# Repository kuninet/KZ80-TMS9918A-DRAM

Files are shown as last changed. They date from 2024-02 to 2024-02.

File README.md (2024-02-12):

# KZ80シリーズ TMS9918A ビデオボード(DRAM版)

## 概要

* SBC8080バスにつながるTMS9918Aビデオボードのプロジェクトです。
* 以下のリポジトリからFORKしたかたちで、SRAM版からDRAM版へ変更したリポジトリです。
  * https://github.com/kuninet/KZ80-TMS9918A

### 4464 64kbit x 4bit DRAM版

#### 回路図

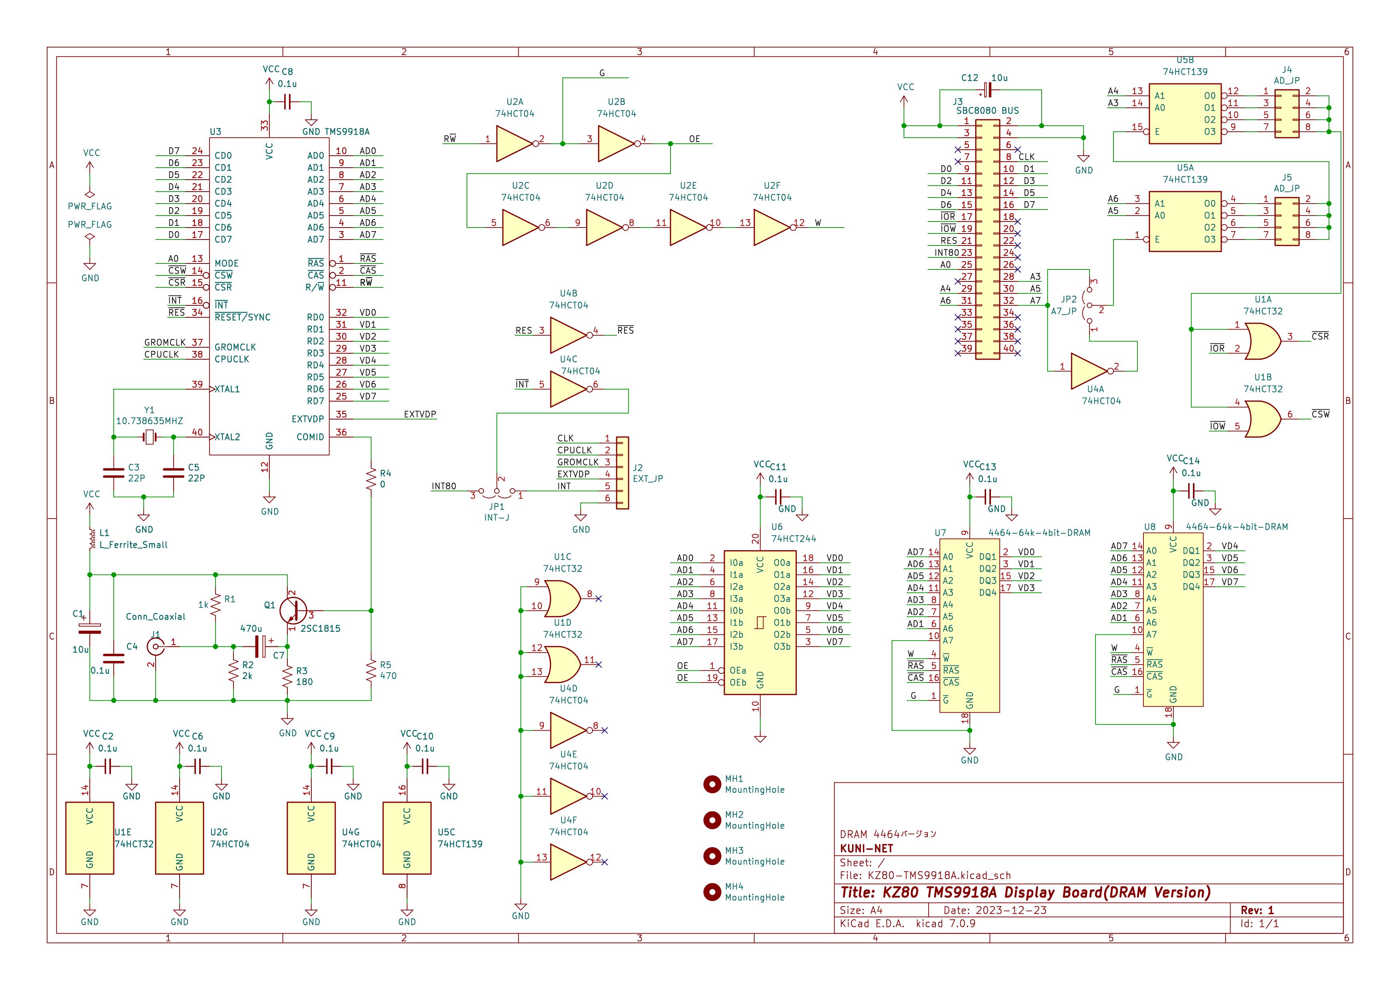
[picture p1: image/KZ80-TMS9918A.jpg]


#### 部品表

[KiCAD/KZ80-TMS9918A.csv](KiCAD/KZ80-TMS9918A.csv)

### MB8118 16kbit x 1bit DRAM版

#### 回路図

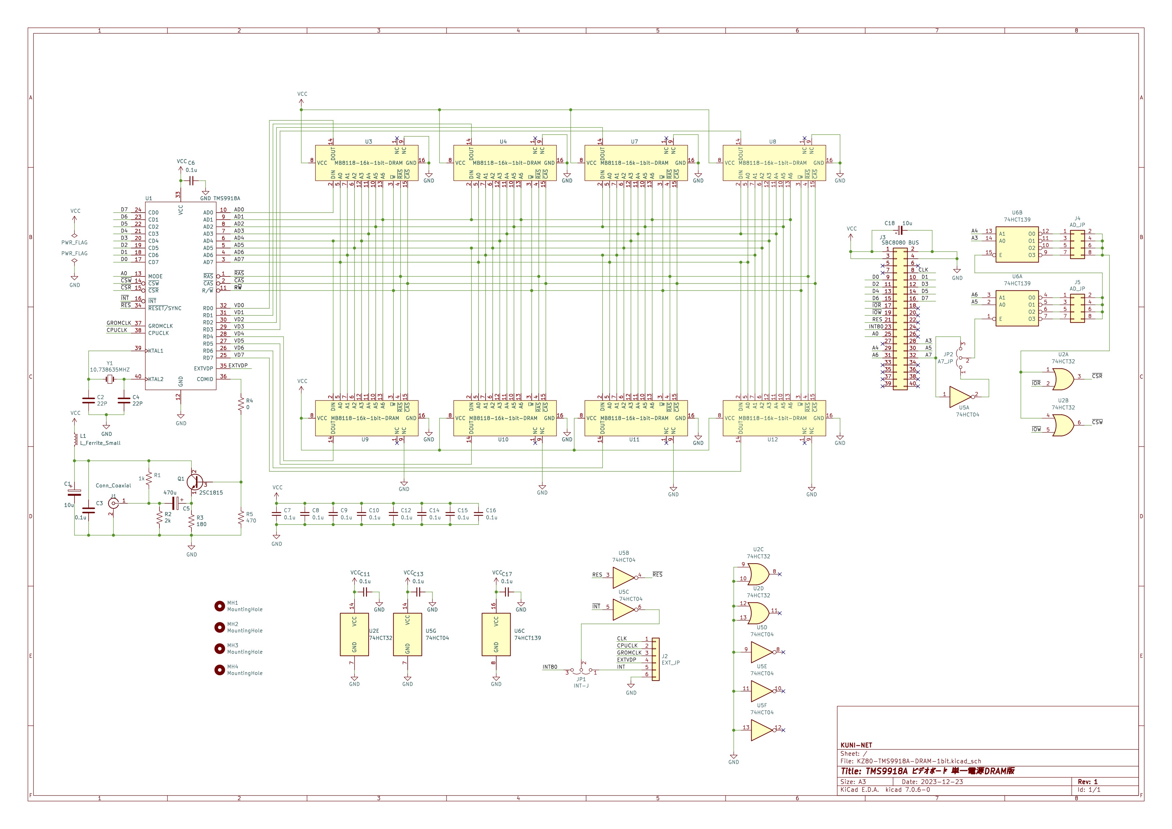
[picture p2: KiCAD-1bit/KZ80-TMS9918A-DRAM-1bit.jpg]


#### 部品表

[KiCAD-1bit/KZ80-TMS9918A-DRAM-1bit.csv](KiCAD-1bit/KZ80-TMS9918A-DRAM-1bit.csv)

## ジャンパ設定

* I/Oアドレスをジャンパ設定で変更できます。
  * JP2、J5、J4の設定値を加算したものがI/Oアドレスとなります。

### ☆★ プリント基板のバージョンによってはシルク印刷が正しくないものがありますので、回路図と見比べてください。☆★

### JP2:アドレス線A7ジャンパ

|端子|設定|
|:--|:--|
|1-2|$80|
|2-3|$00|

### J5:アドレス線A6,A5ジャンパ

|端子|設定|
|:--|:--|
|1-2|$00|
|3-4|$20|
|5-6|$40|
|7-8|$60|

### J4:アドレス線A4,A3ジャンパ

|端子|設定|
|:--|:--|
|1-2|$00|
|3-4|$08|
|5-6|$10|
|7-8|$18|

## ライセンス
* 本プロジェクトのデータはMITライセンスのもとで公開します。

## 参考
* 64k x 4bit版は、以下のサイトの情報を参考に作成しています。ありがとうございます。
  * https://digicoolthings.com/tms9929a-vdp-rediscovery-and-alternative-vram-solution/

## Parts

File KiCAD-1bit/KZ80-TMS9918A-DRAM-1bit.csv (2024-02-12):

Item | Qty | Reference(s) | Value | comments | LibPart | Footprint | Datasheet | DNP
1 | 1 | C1 | 10u | 電解コンデンサ | Device:C_Polarized | Capacitor_THT:CP_Radial_D5.0mm_P2.50mm | ~
2 | 2 | C2, C4 | 22P | セラミックコンデンサ | Device:C | Capacitor_THT:C_Disc_D3.0mm_W1.6mm_P2.50mm | ~
3 | 1 | C3 | 0.1u | セラミックコンデンサ | Device:C | Capacitor_THT:C_Disc_D3.0mm_W1.6mm_P2.50mm | ~
4 | 1 | C5 | 470u | 電解コンデンサ | Device:C_Polarized | Capacitor_THT:CP_Radial_D5.0mm_P2.50mm | ~
5 | 12 | C6, C7, C8, C9, C10, C11, C12, C13, C14, C15, C16, C17 | 0.1u | セラミックコンデンサ | Device:C_Small | Capacitor_THT:C_Disc_D3.0mm_W1.6mm_P2.50mm | ~
6 | 1 | C18 | 10u | 電解コンデンサ | Device:C_Polarized_Small | Capacitor_THT:CP_Radial_D5.0mm_P2.50mm | ~
7 | 1 | J1 | RJ-2410N/Y | 基板用RCAジャック(秋月電子) | Connector:Conn_Coaxial | RCA:RCAConAE | ~
8 | 1 | J2 | EXT_JP | L型ピンヘッダ | Connector_Generic:Conn_01x06 | Connector_PinHeader_2.54mm:PinHeader_1x06_P2.54mm_Horizontal | ~
9 | 1 | J3 | SBC8080 BUS | ボックスヘッダ | Connector_Generic:Conn_02x20_Odd_Even | Connector_PinHeader_2.54mm:PinHeader_2x20_P2.54mm_Horizontal | ~
10 | 2 | J4, J5 | AD_JP | ピンヘッダ(2列) | Connector_Generic:Conn_02x04_Odd_Even | Connector_PinHeader_2.54mm:PinHeader_2x04_P2.54mm_Vertical | ~
11 | 1 | JP1 | INT-J | ピンヘッダ(1列) | Jumper:Jumper_3_Open | Connector_PinHeader_2.54mm:PinHeader_1x03_P2.54mm_Vertical | ~
12 | 1 | JP2 | A7_JP | ピンヘッダ(1列) | Jumper:Jumper_3_Open | Connector_PinHeader_2.54mm:PinHeader_1x03_P2.54mm_Vertical | ~
13 | 1 | L1 | BL01RN1A1D2など | EMI除去フィルタなど | Device:L_Ferrite_Small | Resistor_THT:R_Axial_DIN0207_L6.3mm_D2.5mm_P10.16mm_Horizontal | ~
14 | 4 | MH1, MH2, MH3, MH4 | MountingHole | 基板穴(部品ではない) | Mechanical:MountingHole | MountingHole:MountingHole_3.2mm_M3 | ~
15 | 1 | Q1 | 2SC1815 | トランジスタ | Transistor_BJT:2SC1815 | Package_TO_SOT_THT:TO-92_Inline_Wide | https://media.digikey.com/pdf/Data%20Sheets/Toshiba%20PDFs/2SC1815.pdf
16 | 1 | R1 | 1k | 抵抗器 | Device:R_US | Resistor_THT:R_Axial_DIN0207_L6.3mm_D2.5mm_P10.16mm_Horizontal | ~
17 | 1 | R2 | 2k | 抵抗器 | Device:R_US | Resistor_THT:R_Axial_DIN0207_L6.3mm_D2.5mm_P10.16mm_Horizontal | ~
18 | 1 | R3 | 180 | 抵抗器 | Device:R_US | Resistor_THT:R_Axial_DIN0207_L6.3mm_D2.5mm_P10.16mm_Horizontal | ~
19 | 1 | R4 | 0 | 抵抗器(導線で接続でOK) | Device:R_US | Resistor_THT:R_Axial_DIN0207_L6.3mm_D2.5mm_P10.16mm_Horizontal | ~
20 | 1 | R5 | 470 | 抵抗器 | Device:R_US | Resistor_THT:R_Axial_DIN0207_L6.3mm_D2.5mm_P10.16mm_Horizontal | ~
21 | 1 | U1 | TMS9918A | ビデオIC | TMS9918A:TMS9918A | Package_DIP:DIP-40_W15.24mm_Socket
22 | 1 | U2 | 74HCT32 | ロジックIC | 74xx:74LS32 | Package_DIP:DIP-14_W7.62mm_Socket | http://www.ti.com/lit/gpn/sn74LS32
23 | 8 | U3, U4, U7, U8, U9, U10, U11, U12 | MB8118-16k-1bit-DRAM | DRAM | DRAM:MB8118-16k-1bit-DRAM | Package_DIP:DIP-16_W7.62mm_Socket
24 | 1 | U5 | 74HCT04 | ロジックIC | 74xx:74LS04 | Package_DIP:DIP-14_W7.62mm_Socket | http://www.ti.com/lit/gpn/sn74LS04
25 | 1 | U6 | 74HCT139 | ロジックIC | 74xx:74LS139 | Package_DIP:DIP-16_W7.62mm_Socket | http://www.ti.com/lit/ds/symlink/sn74ls139a.pdf
26 | 1 | Y1 | 10.738635MHZ | 水晶振動子 | Device:Crystal_Small | Crystal:Crystal_HC49-U_Vertical | ~

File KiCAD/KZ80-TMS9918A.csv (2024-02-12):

Item | Qty | Reference(s) | Value | comments | LibPart | Footprint | Datasheet | DNP
1 | 1 | C1 | 10u | 電解コンデンサ | Device:C_Polarized | Capacitor_THT:CP_Radial_D5.0mm_P2.50mm | ~
2 | 8 | C2, C6, C8, C9, C10, C11, C13, C14 | 0.1u | セラミックコンデンサ | Device:C_Small | Capacitor_THT:C_Disc_D3.0mm_W1.6mm_P2.50mm | ~
3 | 2 | C3, C5 | 22P | セラミックコンデンサ | Device:C | Capacitor_THT:C_Disc_D3.0mm_W1.6mm_P2.50mm | ~
4 | 1 | C4 | 0.1u | セラミックコンデンサ | Device:C | Capacitor_THT:C_Disc_D3.0mm_W1.6mm_P2.50mm | ~
5 | 1 | C7 | 470u | 電解コンデンサ | Device:C_Polarized | Capacitor_THT:CP_Radial_D5.0mm_P2.50mm | ~
6 | 1 | C12 | 10u | 電解コンデンサ | Device:C_Polarized_Small | Capacitor_THT:CP_Radial_D5.0mm_P2.50mm | ~
7 | 1 | J1 | RJ-2410N/Y | 基板用RCAジャック(秋月電子) | Connector:Conn_Coaxial | RCACon:RCAConAE | ~
8 | 1 | J2 | EXT_JP | L型ピンヘッダ | Connector_Generic:Conn_01x06 | Connector_PinHeader_2.54mm:PinHeader_1x06_P2.54mm_Horizontal | ~
9 | 1 | J3 | SBC8080 BUS | ボックスヘッダ | Connector_Generic:Conn_02x20_Odd_Even | Connector_PinHeader_2.54mm:PinHeader_2x20_P2.54mm_Horizontal | ~
10 | 2 | J4, J5 | AD_JP | ピンヘッダ(2列) | Connector_Generic:Conn_02x04_Odd_Even | Connector_PinHeader_2.54mm:PinHeader_2x04_P2.54mm_Vertical | ~
11 | 1 | JP1 | INT-J | ピンヘッダ(1列) | Jumper:Jumper_3_Open | Connector_PinHeader_2.54mm:PinHeader_1x03_P2.54mm_Vertical | ~
12 | 1 | JP2 | A7_JP | ピンヘッダ(1列) | Jumper:Jumper_3_Open | Connector_PinHeader_2.54mm:PinHeader_1x03_P2.54mm_Vertical | ~
13 | 1 | L1 | BL01RN1A1D2など | EMI除去フィルタなど | Device:L_Ferrite_Small | Resistor_THT:R_Axial_DIN0207_L6.3mm_D2.5mm_P10.16mm_Horizontal | ~
14 | 4 | MH1, MH2, MH3, MH4 | MountingHole | 基板穴(部品ではない) | Mechanical:MountingHole | MountingHole:MountingHole_3.2mm_M3 | ~
15 | 1 | Q1 | 2SC1815 | トランジスタ | Transistor_BJT:2SC1815 | Package_TO_SOT_THT:TO-92_Inline_Wide | https://media.digikey.com/pdf/Data%20Sheets/Toshiba%20PDFs/2SC1815.pdf
16 | 1 | R1 | 1k | 抵抗器 | Device:R_US | Resistor_THT:R_Axial_DIN0207_L6.3mm_D2.5mm_P10.16mm_Horizontal | ~
17 | 1 | R2 | 2k | 抵抗器 | Device:R_US | Resistor_THT:R_Axial_DIN0207_L6.3mm_D2.5mm_P10.16mm_Horizontal | ~
18 | 1 | R3 | 180 | 抵抗器 | Device:R_US | Resistor_THT:R_Axial_DIN0207_L6.3mm_D2.5mm_P10.16mm_Horizontal | ~
19 | 1 | R4 | 0 | 抵抗器(導線で接続でOK) | Device:R_US | Resistor_THT:R_Axial_DIN0207_L6.3mm_D2.5mm_P10.16mm_Horizontal | ~
20 | 1 | R5 | 470 | 抵抗器 | Device:R_US | Resistor_THT:R_Axial_DIN0207_L6.3mm_D2.5mm_P10.16mm_Horizontal | ~
21 | 1 | U1 | 74HCT32 | ロジックIC | 74xx:74LS32 | Package_DIP:DIP-14_W7.62mm_Socket | http://www.ti.com/lit/gpn/sn74LS32
22 | 2 | U2, U4 | 74HCT04 | ロジックIC | 74xx:74LS04 | Package_DIP:DIP-14_W7.62mm_Socket | http://www.ti.com/lit/gpn/sn74LS04
23 | 1 | U3 | TMS9918A | ビデオIC | TMS9918A:TMS9918A | Package_DIP:DIP-40_W15.24mm_Socket
24 | 1 | U5 | 74HCT139 | ロジックIC | 74xx:74LS139 | Package_DIP:DIP-16_W7.62mm_Socket | http://www.ti.com/lit/ds/symlink/sn74ls139a.pdf
25 | 1 | U6 | 74HCT244 | ロジックIC | 74xx:74LS244 | Package_DIP:DIP-20_W7.62mm_Socket | http://www.ti.com/lit/ds/symlink/sn74ls244.pdf
26 | 2 | U7, U8 | 4464-64k-4bit-DRAM | DRAM | DRAM:4416-16k-4bit-DRAM | Package_DIP:DIP-18_W7.62mm_Socket
27 | 1 | Y1 | 10.738635MHZ | 水晶振動子 | Device:Crystal_Small | Crystal:Crystal_HC49-U_Vertical | ~

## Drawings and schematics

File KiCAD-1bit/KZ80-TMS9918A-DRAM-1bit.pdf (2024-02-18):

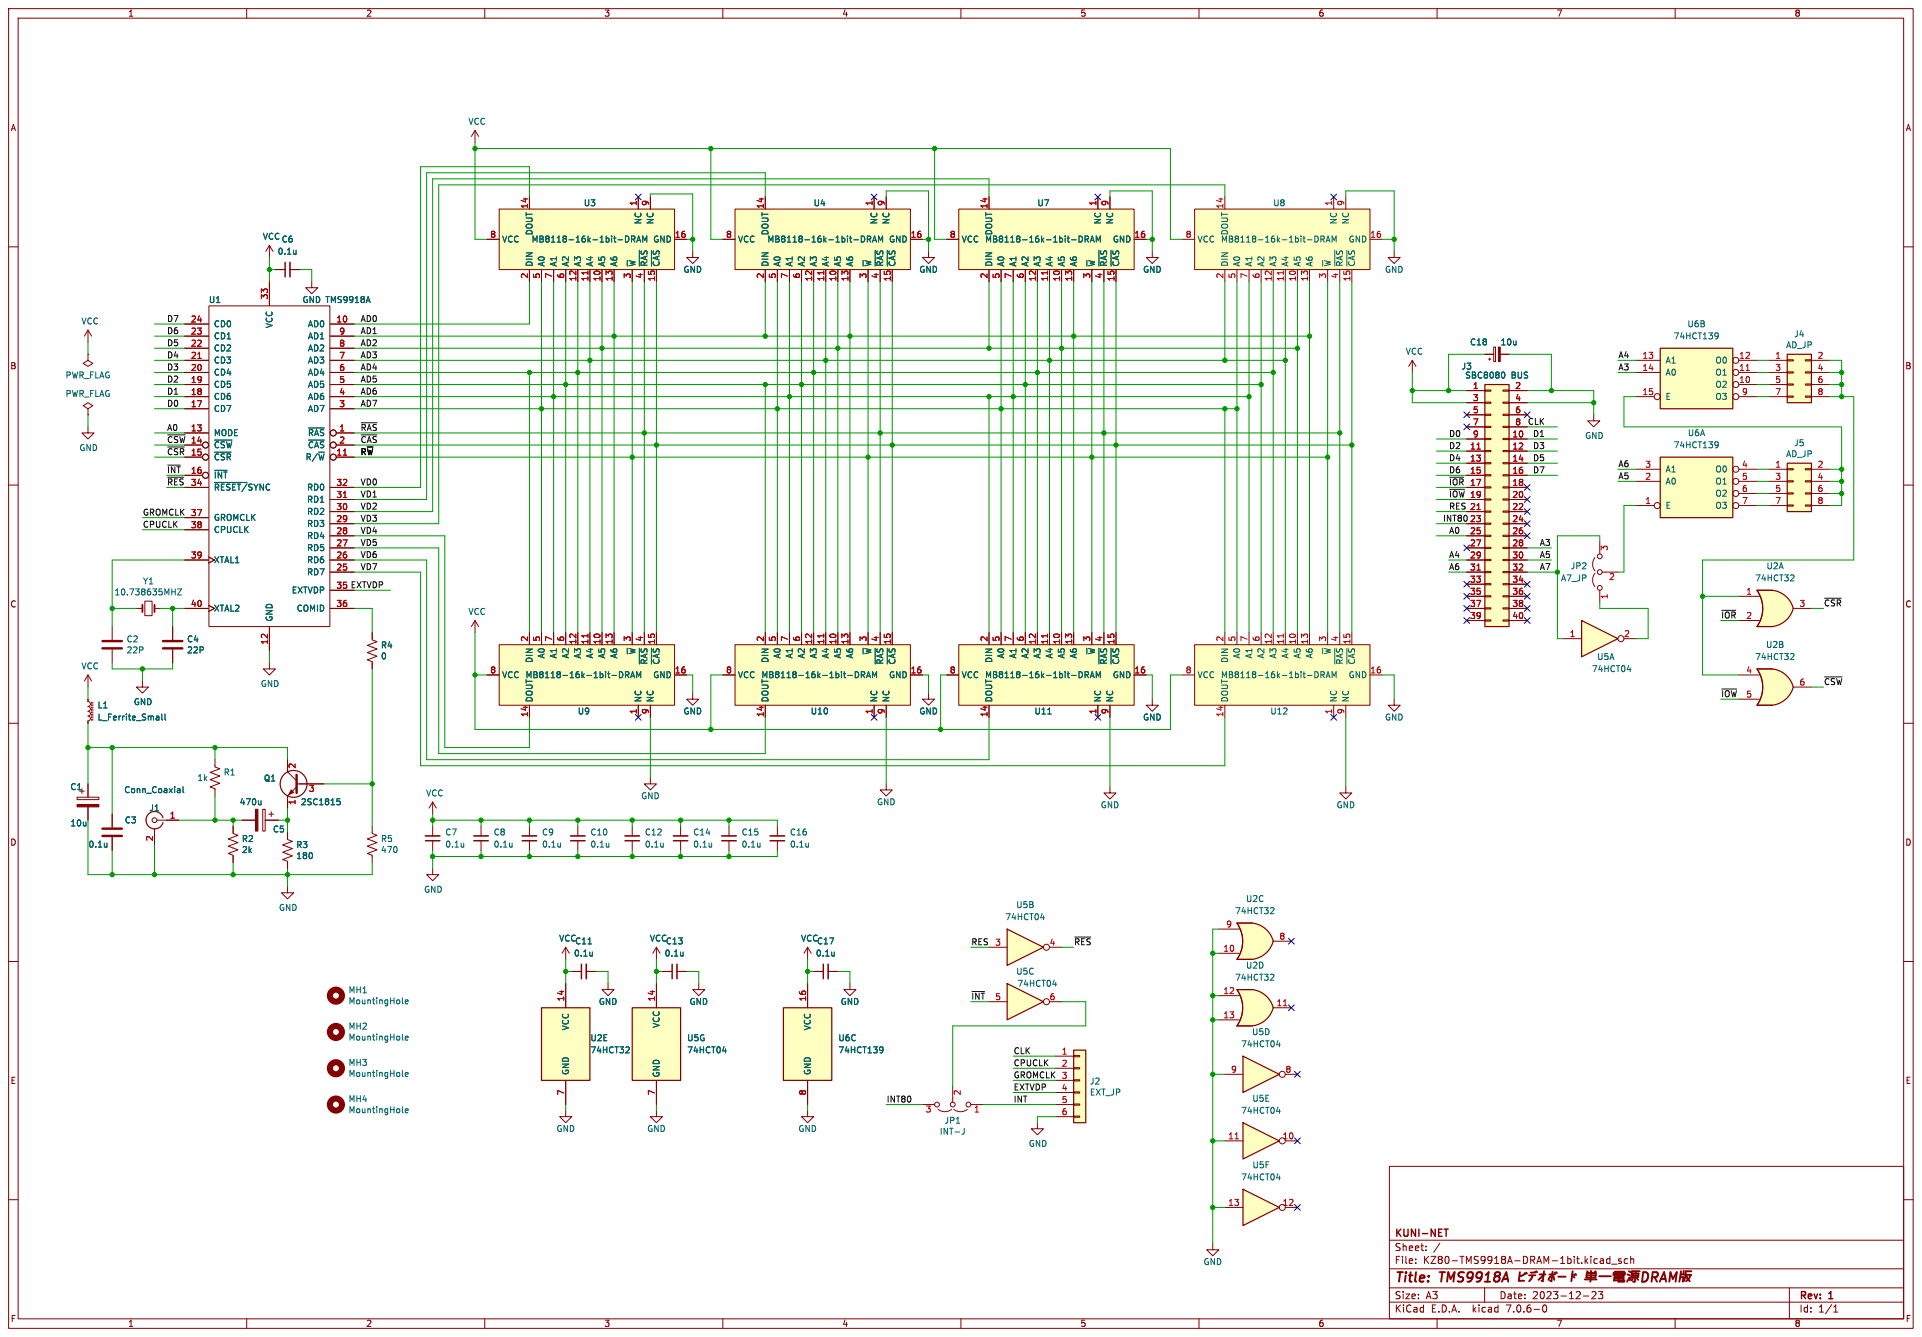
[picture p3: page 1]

File: KZ80-TMS9918A-DRAM-1bit.kicad_sch Sheet: / KUNI-NET NC

1 A5 10 A4 11 A3 12 A6 13 DOUT 14 ~{CAS} 15 GND 16 DIN

Id: 1/1 Title: TMS9918A þÿ0Ó0Ç0ª0Ü0ü0É þÿSXN–ûn•DRAMrH

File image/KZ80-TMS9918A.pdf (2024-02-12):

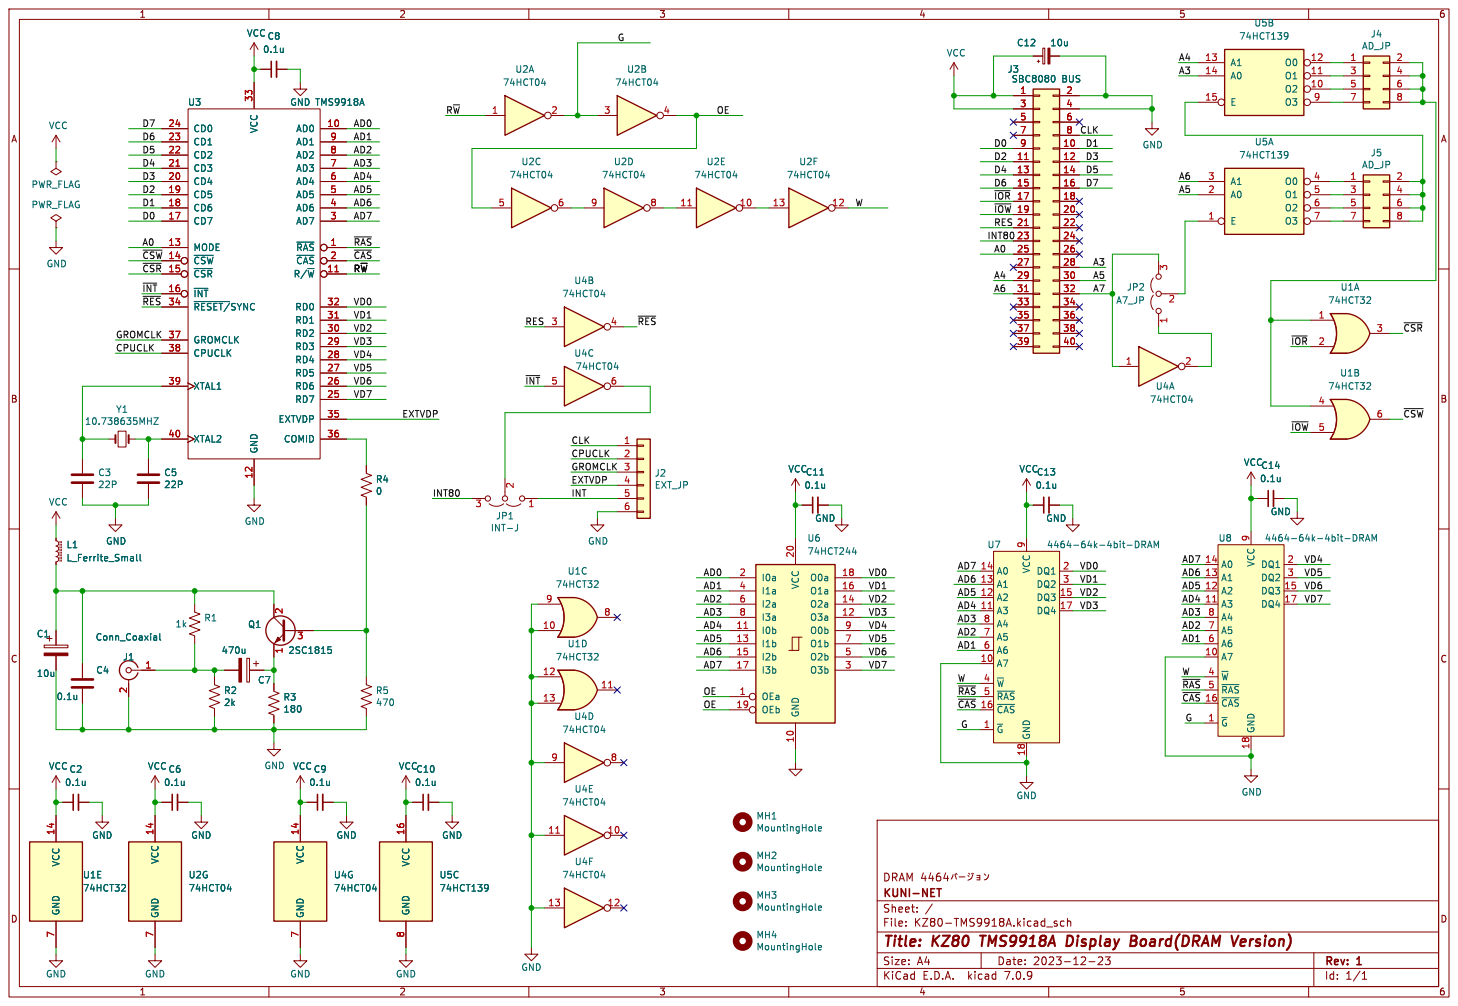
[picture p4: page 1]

Id: 1/1 Title: KZ80 TMS9918A Display Board(DRAM Version) File: KZ80-TMS9918A.kicad_sch Sheet: / KUNI-NET DRAM þÿ44640Ð0ü0¸0ç0ó VCC 14 GND

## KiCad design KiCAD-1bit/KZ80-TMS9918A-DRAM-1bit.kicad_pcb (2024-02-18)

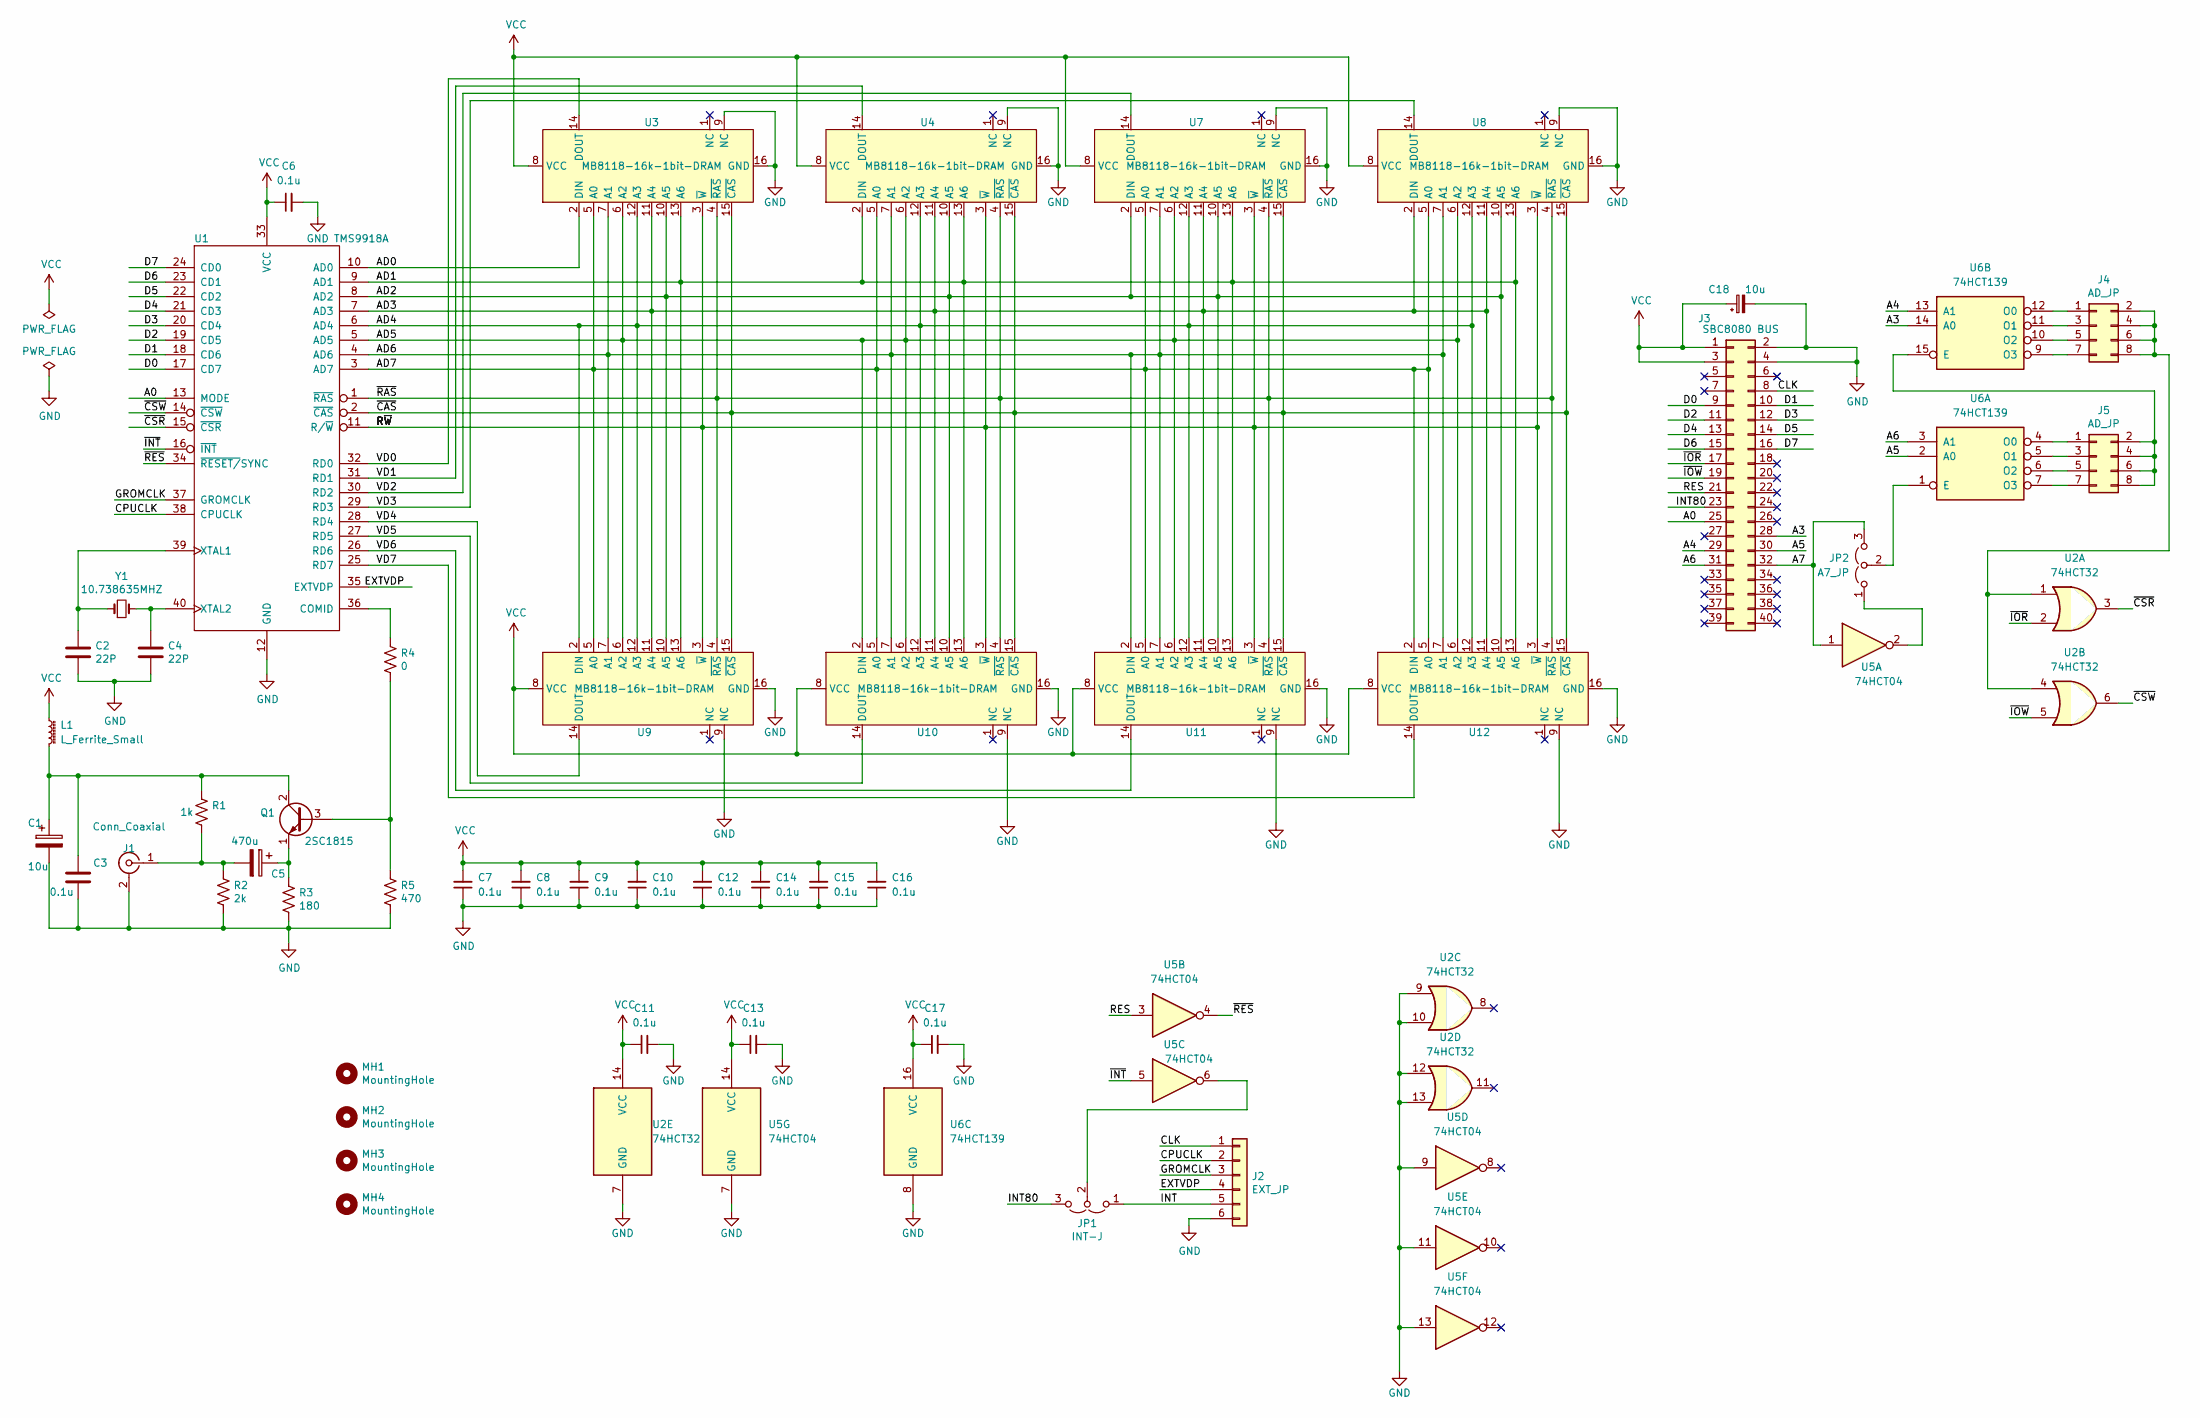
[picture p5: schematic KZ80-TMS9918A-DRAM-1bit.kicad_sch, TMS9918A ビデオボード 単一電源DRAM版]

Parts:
C1, C18: 10u; CP_Radial_D5.0mm_P2.50mm
C2, C4: 22P; C_Disc_D3.0mm_W1.6mm_P2.50mm
C3, C6, C7, C8, C9, C10, C11, C12, C13, C14, C15, C16, C17: 0.1u; C_Disc_D3.0mm_W1.6mm_P2.50mm
C5: 470u; CP_Radial_D5.0mm_P2.50mm
J1: Conn_Coaxial; RCAConAE
J2: EXT_JP; PinHeader_1x06_P2.54mm_Horizontal
J3: SBC8080 BUS; PinHeader_2x20_P2.54mm_Horizontal
J4, J5: AD_JP; PinHeader_2x04_P2.54mm_Vertical
JP1: INT-J; PinHeader_1x03_P2.54mm_Vertical
JP2: A7_JP; PinHeader_1x03_P2.54mm_Vertical
L1: L_Ferrite_Small; R_Axial_DIN0207_L6.3mm_D2.5mm_P10.16mm_Horizontal
MH1, MH2, MH3, MH4: MountingHole; MountingHole_3.2mm_M3
Q1: 2SC1815; TO-92_Inline_Wide
R1: 1k; R_Axial_DIN0207_L6.3mm_D2.5mm_P10.16mm_Horizontal
R2: 2k; R_Axial_DIN0207_L6.3mm_D2.5mm_P10.16mm_Horizontal
R3: 180; R_Axial_DIN0207_L6.3mm_D2.5mm_P10.16mm_Horizontal
R4: 0; R_Axial_DIN0207_L6.3mm_D2.5mm_P10.16mm_Horizontal
R5: 470; R_Axial_DIN0207_L6.3mm_D2.5mm_P10.16mm_Horizontal
U1: TMS9918A; DIP-40_W15.24mm_Socket
U2: 74HCT32; DIP-14_W7.62mm_Socket
U3, U4, U7, U8, U9, U10, U11, U12: MB8118-16k-1bit-DRAM; DIP-16_W7.62mm_Socket
U5: 74HCT04; DIP-14_W7.62mm_Socket
U6: 74HCT139; DIP-16_W7.62mm_Socket
Y1: 10.738635MHZ; Crystal_HC49-U_Vertical

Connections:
/A0: J3.25, U1.13 (MODE)
/A3: J3.28, U6.14 (A0)
/A4: J3.29, U6.13 (A1)
/A5: J3.30, U6.2 (A0)
/A6: J3.31, U6.3 (A1)
/A7: J3.32, JP2.3 (B), U5.1
/AD0: U1.10 (AD0), U3.2 (DIN)
/AD1: U1.9 (AD1), U3.13 (A6), U4.2 (DIN), U4.13 (A6), U7.13 (A6), U8.13 (A6), U9.13 (A6), U10.13 (A6), U11.13 (A6), U12.13 (A6)
/AD2: U1.8 (AD2), U3.10 (A5), U4.10 (A5), U7.2 (DIN), U7.10 (A5), U8.10 (A5), U9.10 (A5), U10.10 (A5), U11.10 (A5), U12.10 (A5)
/AD3: U1.7 (AD3), U3.11 (A4), U4.11 (A4), U7.11 (A4), U8.2 (DIN), U8.11 (A4), U9.11 (A4), U10.11 (A4), U11.11 (A4), U12.11 (A4)
/AD4: U1.6 (AD4), U3.12 (A3), U4.12 (A3), U7.12 (A3), U8.12 (A3), U9.2 (DIN), U9.12 (A3), U10.12 (A3), U11.12 (A3), U12.12 (A3)
/AD5: U1.5 (AD5), U3.6 (A2), U4.6 (A2), U7.6 (A2), U8.6 (A2), U9.6 (A2), U10.2 (DIN), U10.6 (A2), U11.6 (A2), U12.6 (A2)
/AD6: U1.4 (AD6), U3.7 (A1), U4.7 (A1), U7.7 (A1), U8.7 (A1), U9.7 (A1), U10.7 (A1), U11.2 (DIN), U11.7 (A1), U12.7 (A1)
/AD7: U1.3 (AD7), U3.5 (A0), U4.5 (A0), U7.5 (A0), U8.5 (A0), U9.5 (A0), U10.5 (A0), U11.5 (A0), U12.2 (DIN), U12.5 (A0)
/CLK: J2.1, J3.8
/CPUCLK: J2.2, U1.38 (CPUCLK)
/D0: J3.9, U1.17 (CD7)
/D1: J3.10, U1.18 (CD6)
/D2: J3.11, U1.19 (CD5)
/D3: J3.12, U1.20 (CD4)
/D4: J3.13, U1.21 (CD3)
/D5: J3.14, U1.22 (CD2)
/D6: J3.15, U1.23 (CD1)
/D7: J3.16, U1.24 (CD0)
/EXTVDP: J2.4, U1.35 (EXTVDP)
/GROMCLK: J2.3, U1.37 (GROMCLK)
/INT: J2.5, JP1.1 (A)
/INT80: J3.23, JP1.3 (B)
/RES: J3.21, U5.3
/R~W: U1.11 (R/~W), U3.3 (~W), U4.3 (~W), U7.3 (~W), U8.3 (~W), U9.3 (~W), U10.3 (~W), U11.3 (~W), U12.3 (~W)
/VD0: U1.32 (RD0), U3.14 (DOUT)
/VD1: U1.31 (RD1), U4.14 (DOUT)
/VD2: U1.30 (RD2), U7.14 (DOUT)
/VD3: U1.29 (RD3), U8.14 (DOUT)
/VD4: U1.28 (RD4), U9.14 (DOUT)
/VD5: U1.27 (RD5), U10.14 (DOUT)
/VD6: U1.26 (RD6), U11.14 (DOUT)
/VD7: U1.25 (RD7), U12.14 (DOUT)
/~CAS: U1.2 (~CAS), U3.15 (~CAS), U4.15 (~CAS), U7.15 (~CAS), U8.15 (~CAS), U9.15 (~CAS), U10.15 (~CAS), U11.15 (~CAS), U12.15 (~CAS)
/~CSR: U1.15 (~CSR), U2.3
/~CSW: U1.14 (~CSW), U2.6
/~INT: U1.16 (~INT), U5.5
/~IOR: J3.17, U2.2
/~IOW: J3.19, U2.5
/~RAS: U1.1 (~RAS), U3.4 (~RAS), U4.4 (~RAS), U7.4 (~RAS), U8.4 (~RAS), U9.4 (~RAS), U10.4 (~RAS), U11.4 (~RAS), U12.4 (~RAS)
/~RES: U1.34 (~RESET/SYNC), U5.4
GND: C1.2, C2.2, C3.2, C4.2, C6.2, C7.1, C8.1, C9.1, C10.1, C11.2, C12.1, C13.2, C14.1, C15.1, C16.1, C17.2, C18.2, J1.2 (Ext), J2.6, J3.2, J3.4, R2.2, R3.2, R5.2, U1.12 (GND), U2.7 (GND), U2.9, U2.10, U2.12, U2.13, U3.9 (NC), U3.16 (GND), U4.9 (NC), U4.16 (GND), U5.7 (GND), U5.9, U5.11, U5.13, U6.8 (GND), U7.9 (NC), U7.16 (GND), U8.9 (NC), U8.16 (GND), U9.9 (NC), U9.16 (GND), U10.9 (NC), U10.16 (GND), U11.9 (NC), U11.16 (GND), U12.9 (NC), U12.16 (GND)
unnamed: C5.2, J1.1 (In), R1.2, R2.1
unnamed: J4.1, U6.12 (O0)
unnamed: J4.2, J4.4, J4.6, J4.8, U2.1, U2.4
unnamed: J4.3, U6.11 (O1)
unnamed: J4.5, U6.10 (O2)
unnamed: J4.7, U6.9 (O3)
unnamed: J5.1, U6.4 (O0)
unnamed: J5.2, J5.4, J5.6, J5.8, U6.15 (E)
unnamed: J5.3, U6.5 (O1)
unnamed: J5.5, U6.6 (O2)
unnamed: J5.7, U6.7 (O3)
unnamed: JP1.2 (C), U5.6
unnamed: JP2.1 (A), U5.2
unnamed: JP2.2 (C), U6.1 (E)
unnamed: Q1.3 (B), R4.2, R5.1
unnamed: C1.1, C3.1, L1.2, Q1.2 (C), R1.1
unnamed: C5.1, Q1.1 (E), R3.1
unnamed: R4.1, U1.36 (COMID)
unnamed: C2.1, U1.39 (XTAL1), Y1.1
unnamed: C4.1, U1.40 (XTAL2), Y1.2
VCC: C6.1, C7.2, C8.2, C9.2, C10.2, C11.1, C12.2, C13.1, C14.2, C15.2, C16.2, C17.1, C18.1, J3.1, J3.3, L1.1, U1.33 (VCC), U2.14 (VCC), U3.8 (VCC), U4.8 (VCC), U5.14 (VCC), U6.16 (VCC), U7.8 (VCC), U8.8 (VCC), U9.8 (VCC), U10.8 (VCC), U11.8 (VCC), U12.8 (VCC)

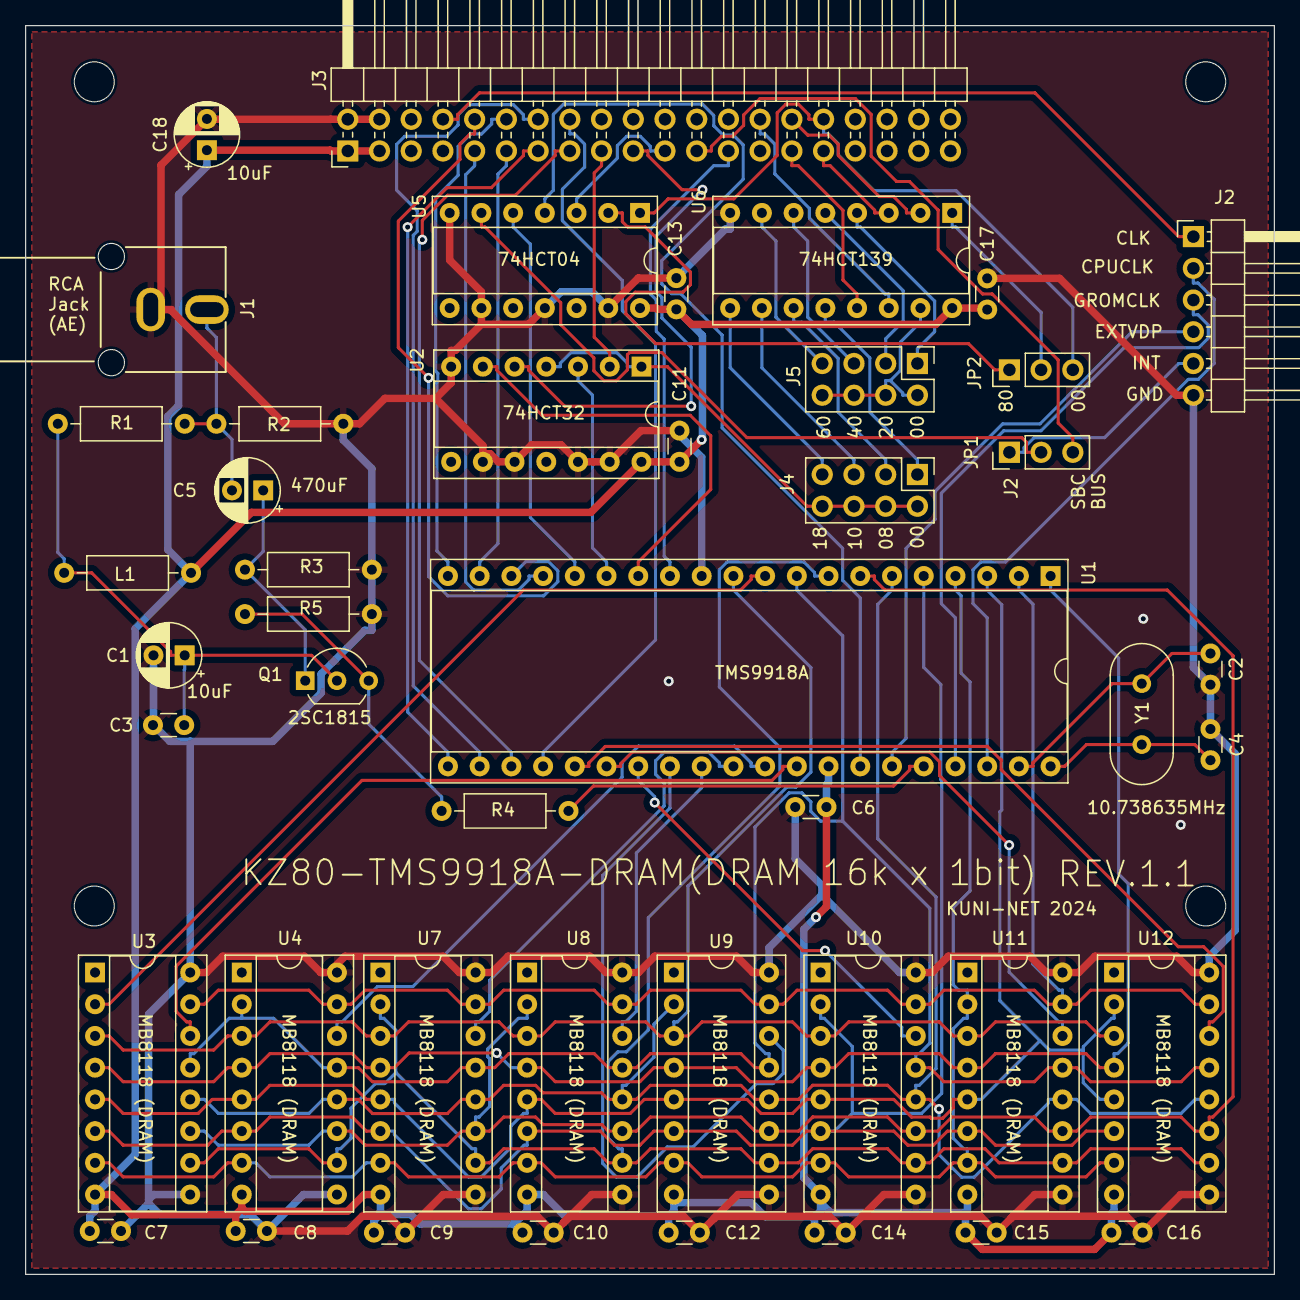
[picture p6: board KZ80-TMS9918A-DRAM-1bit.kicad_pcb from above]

Board: 2 copper layers, 100.0 x 100.0 mm, 49 parts (0 on the bottom side), 68 nets.

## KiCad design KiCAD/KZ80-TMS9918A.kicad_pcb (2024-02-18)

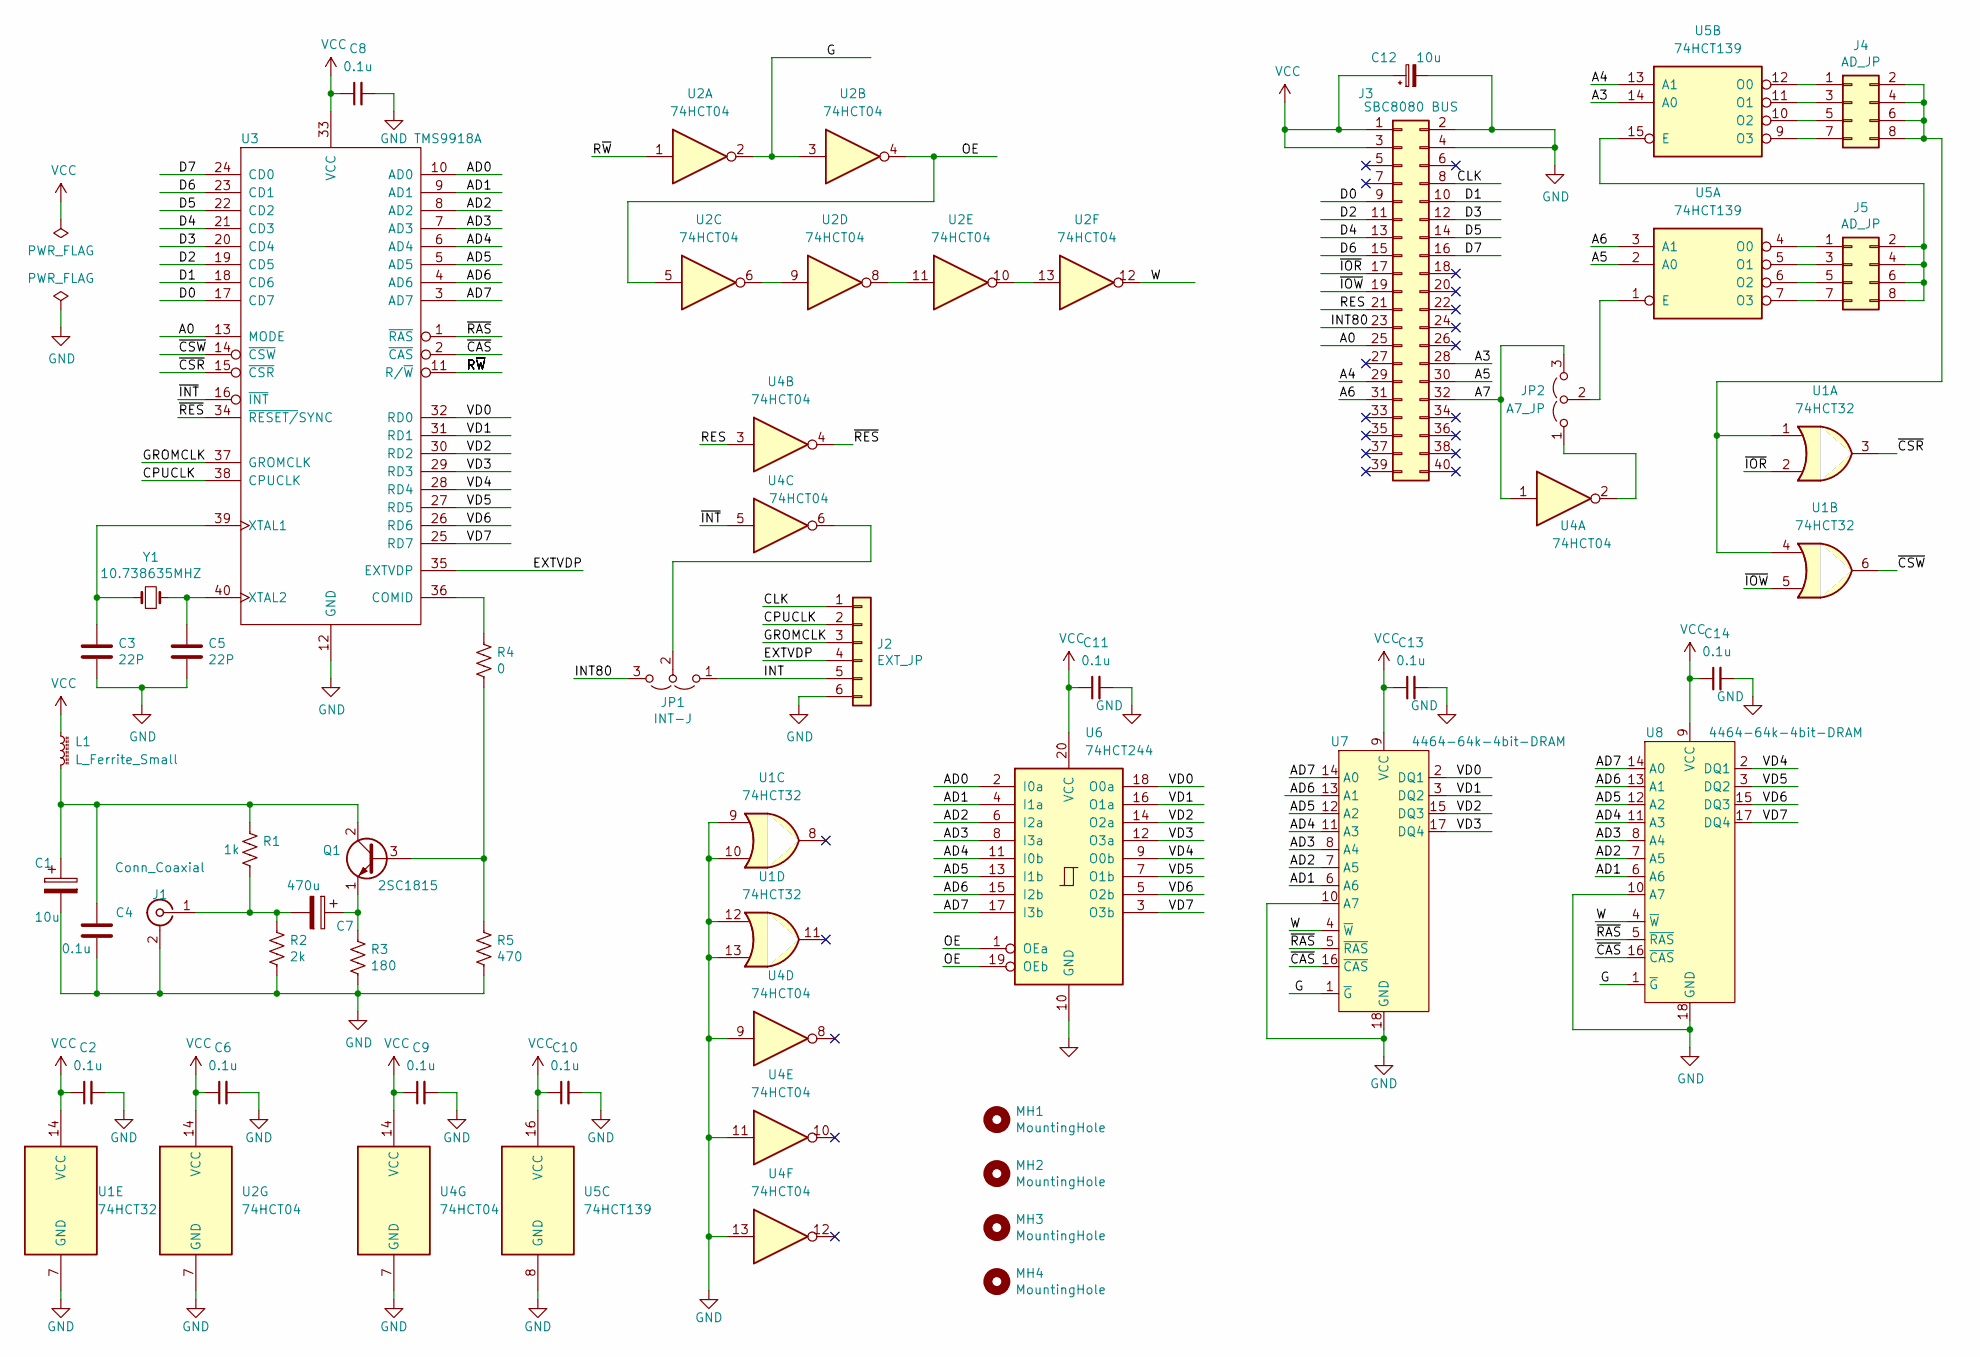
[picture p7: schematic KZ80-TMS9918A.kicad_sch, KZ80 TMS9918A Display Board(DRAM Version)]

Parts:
C1, C12: 10u; CP_Radial_D5.0mm_P2.50mm
C2, C4, C6, C8, C9, C10, C11, C13, C14: 0.1u; C_Disc_D3.0mm_W1.6mm_P2.50mm
C3, C5: 22P; C_Disc_D3.0mm_W1.6mm_P2.50mm
C7: 470u; CP_Radial_D5.0mm_P2.50mm
J1: Conn_Coaxial; RCAConAE
J2: EXT_JP; PinHeader_1x06_P2.54mm_Horizontal
J3: SBC8080 BUS; PinHeader_2x20_P2.54mm_Horizontal
J4, J5: AD_JP; PinHeader_2x04_P2.54mm_Vertical
JP1: INT-J; PinHeader_1x03_P2.54mm_Vertical
JP2: A7_JP; PinHeader_1x03_P2.54mm_Vertical
L1: L_Ferrite_Small; R_Axial_DIN0207_L6.3mm_D2.5mm_P10.16mm_Horizontal
MH1, MH2, MH3, MH4: MountingHole; MountingHole_3.2mm_M3
Q1: 2SC1815; TO-92_Inline_Wide
R1: 1k; R_Axial_DIN0207_L6.3mm_D2.5mm_P10.16mm_Horizontal
R2: 2k; R_Axial_DIN0207_L6.3mm_D2.5mm_P10.16mm_Horizontal
R3: 180; R_Axial_DIN0207_L6.3mm_D2.5mm_P10.16mm_Horizontal
R4: 0; R_Axial_DIN0207_L6.3mm_D2.5mm_P10.16mm_Horizontal
R5: 470; R_Axial_DIN0207_L6.3mm_D2.5mm_P10.16mm_Horizontal
U1: 74HCT32; DIP-14_W7.62mm_Socket
U2, U4: 74HCT04; DIP-14_W7.62mm_Socket
U3: TMS9918A; DIP-40_W15.24mm_Socket
U5: 74HCT139; DIP-16_W7.62mm_Socket
U6: 74HCT244; DIP-20_W7.62mm_Socket
U7, U8: 4464-64k-4bit-DRAM; DIP-18_W7.62mm_Socket
Y1: 10.738635MHZ; Crystal_HC49-U_Vertical

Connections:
/A0: J3.25, U3.13 (MODE)
/A3: J3.28, U5.14 (A0)
/A4: J3.29, U5.13 (A1)
/A5: J3.30, U5.2 (A0)
/A6: J3.31, U5.3 (A1)
/A7: J3.32, JP2.3 (B), U4.1
/AD0: U3.10 (AD0), U6.2 (I0a)
/AD1: U3.9 (AD1), U6.4 (I1a), U7.6 (A6), U8.6 (A6)
/AD2: U3.8 (AD2), U6.6 (I2a), U7.7 (A5), U8.7 (A5)
/AD3: U3.7 (AD3), U6.8 (I3a), U7.8 (A4), U8.8 (A4)
/AD4: U3.6 (AD4), U6.11 (I0b), U7.11 (A3), U8.11 (A3)
/AD5: U3.5 (AD5), U6.13 (I1b), U7.12 (A2), U8.12 (A2)
/AD6: U3.4 (AD6), U6.15 (I2b), U7.13 (A1), U8.13 (A1)
/AD7: U3.3 (AD7), U6.17 (I3b), U7.14 (A0), U8.14 (A0)
/CLK: J2.1, J3.8
/CPUCLK: J2.2, U3.38 (CPUCLK)
/D0: J3.9, U3.17 (CD7)
/D1: J3.10, U3.18 (CD6)
/D2: J3.11, U3.19 (CD5)
/D3: J3.12, U3.20 (CD4)
/D4: J3.13, U3.21 (CD3)
/D5: J3.14, U3.22 (CD2)
/D6: J3.15, U3.23 (CD1)
/D7: J3.16, U3.24 (CD0)
/EXTVDP: J2.4, U3.35 (EXTVDP)
/G: U2.2, U2.3, U7.1 (~G), U8.1 (~G)
/GROMCLK: J2.3, U3.37 (GROMCLK)
/INT: J2.5, JP1.1 (A)
/INT80: J3.23, JP1.3 (B)
/OE: U2.4, U2.5, U6.1 (OEa), U6.19 (OEb)
/RES: J3.21, U4.3
/R~W: U2.1, U3.11 (R/~W)
/VD0: U3.32 (RD0), U6.18 (O0a), U7.2 (DQ1)
/VD1: U3.31 (RD1), U6.16 (O1a), U7.3 (DQ2)
/VD2: U3.30 (RD2), U6.14 (O2a), U7.15 (DQ3)
/VD3: U3.29 (RD3), U6.12 (O3a), U7.17 (DQ4)
/VD4: U3.28 (RD4), U6.9 (O0b), U8.2 (DQ1)
/VD5: U3.27 (RD5), U6.7 (O1b), U8.3 (DQ2)
/VD6: U3.26 (RD6), U6.5 (O2b), U8.15 (DQ3)
/VD7: U3.25 (RD7), U6.3 (O3b), U8.17 (DQ4)
/W: U2.12, U7.4 (~W), U8.4 (~W)
/~CAS: U3.2 (~CAS), U7.16 (~CAS), U8.16 (~CAS)
/~CSR: U1.3, U3.15 (~CSR)
/~CSW: U1.6, U3.14 (~CSW)
/~INT: U3.16 (~INT), U4.5
/~IOR: J3.17, U1.2
/~IOW: J3.19, U1.5
/~RAS: U3.1 (~RAS), U7.5 (~RAS), U8.5 (~RAS)
/~RES: U3.34 (~RESET/SYNC), U4.4
GND: C1.2, C2.2, C3.2, C4.2, C5.2, C6.2, C8.2, C9.2, C10.2, C11.2, C12.2, C13.2, C14.2, J1.2 (Ext), J2.6, J3.2, J3.4, R2.2, R3.2, R5.2, U1.7 (GND), U1.9, U1.10, U1.12, U1.13, U2.7 (GND), U3.12 (GND), U4.7 (GND), U4.9, U4.11, U4.13, U5.8 (GND), U6.10 (GND), U7.10 (A7), U7.18 (GND), U8.10 (A7), U8.18 (GND)
unnamed: C7.2, J1.1 (In), R1.2, R2.1
unnamed: J4.1, U5.12 (O0)
unnamed: J4.2, J4.4, J4.6, J4.8, U1.1, U1.4
unnamed: J4.3, U5.11 (O1)
unnamed: J4.5, U5.10 (O2)
unnamed: J4.7, U5.9 (O3)
unnamed: J5.1, U5.4 (O0)
unnamed: J5.2, J5.4, J5.6, J5.8, U5.15 (E)
unnamed: J5.3, U5.5 (O1)
unnamed: J5.5, U5.6 (O2)
unnamed: J5.7, U5.7 (O3)
unnamed: JP1.2 (C), U4.6
unnamed: JP2.1 (A), U4.2
unnamed: JP2.2 (C), U5.1 (E)
unnamed: Q1.3 (B), R4.2, R5.1
unnamed: C1.1, C4.1, L1.2, Q1.2 (C), R1.1
unnamed: C7.1, Q1.1 (E), R3.1
unnamed: U2.6, U2.9
unnamed: U2.10, U2.13
unnamed: U2.8, U2.11
unnamed: R4.1, U3.36 (COMID)
unnamed: C3.1, U3.39 (XTAL1), Y1.1
unnamed: C5.1, U3.40 (XTAL2), Y1.2
VCC: C2.1, C6.1, C8.1, C9.1, C10.1, C11.1, C12.1, C13.1, C14.1, J3.1, J3.3, L1.1, U1.14 (VCC), U2.14 (VCC), U3.33 (VCC), U4.14 (VCC), U5.16 (VCC), U6.20 (VCC), U7.9 (VCC), U8.9 (VCC)

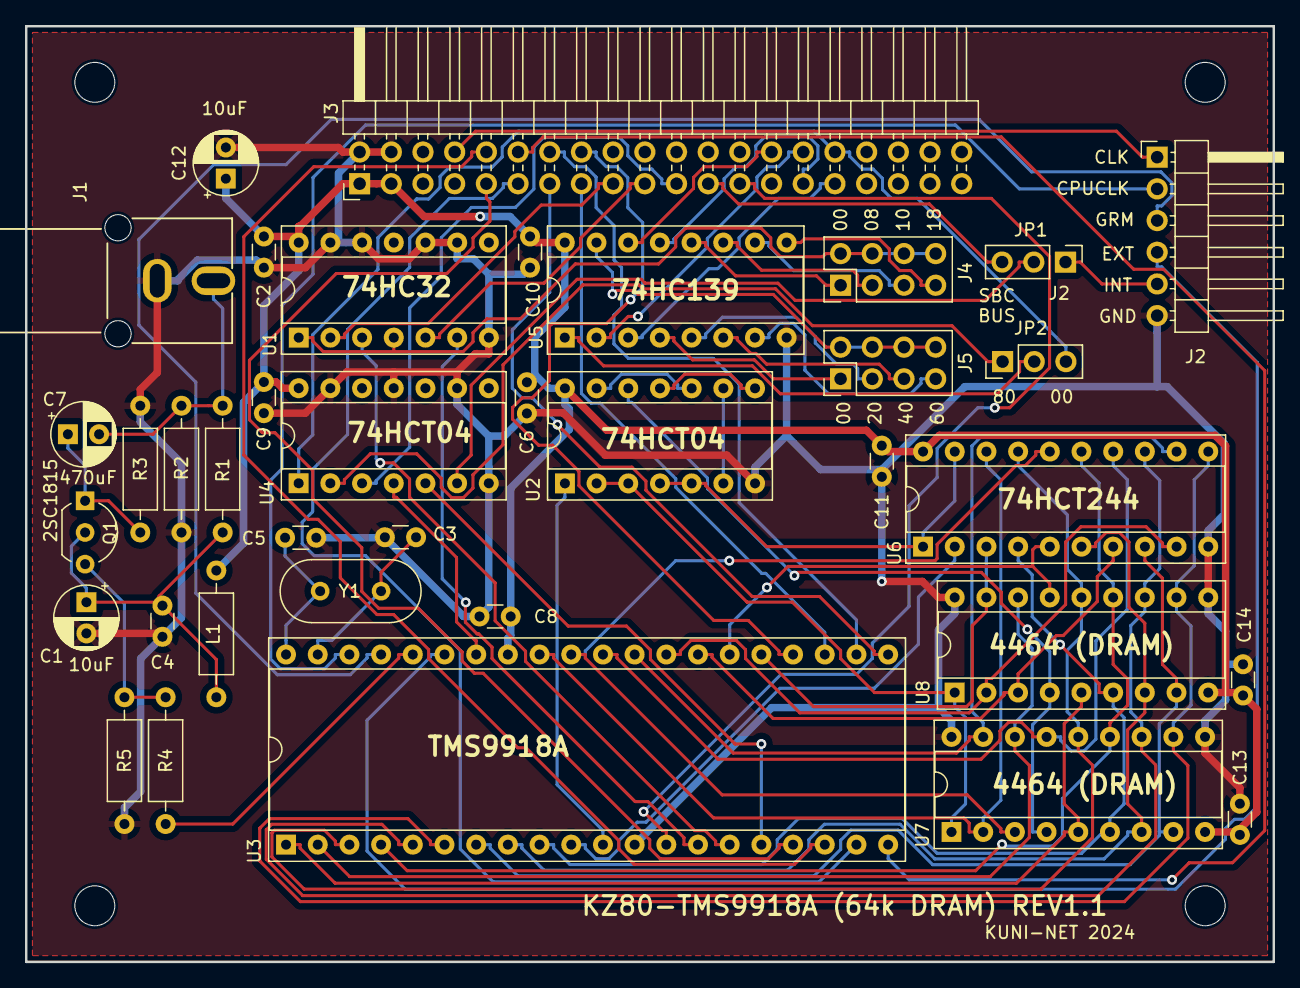
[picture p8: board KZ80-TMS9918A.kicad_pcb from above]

Board: 2 copper layers, 100.0 x 75.0 mm, 41 parts (0 on the bottom side), 74 nets.

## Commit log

2022-08-29 DRAM回路図作成 ベータ版
    [KZ80-TMS9918A.kicad_sch]
2023-12-23 4464 DRAM対応
    [KZ80-TMS9918A.kicad_sch]
2023-12-23 パスコン追加等
    [KZ80-TMS9918A.kicad_sch]
2023-12-23 16k x 1bit版 回路図など作成
    [KZ80-TMS9918A-DRAM-1bit.kicad_pcb, KZ80-TMS9918A-DRAM-1bit.kicad_sch]
2023-12-24 回路図バグ修正
    [KZ80-TMS9918A-DRAM-1bit.kicad_sch]
2024-01-01 回路図イメージデータ再出力
2024-01-01 DRAM 16kx1bit版プリントパターン作成
    [KZ80-TMS9918A-DRAM-1bit-B_Cu.gbl, KZ80-TMS9918A-DRAM-1bit-B_Mask.gbs, KZ80-TMS9918A-DRAM-1bit-B_Paste.gbp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]
2024-01-03 64k DRAM版 ガーバー出力
    [KZ80-TMS9918A-DRAM.GBL, KZ80-TMS9918A-DRAM.GBO, KZ80-TMS9918A-DRAM.GBS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]
2024-02-12 シルク印刷間違い修正(64bit、16kbit両方) REV1.1ガーバー出力
    [KZ80-TMS9918A-DRAM-1bit.GBL, KZ80-TMS9918A-DRAM-1bit.GBO, KZ80-TMS9918A-DRAM-1bit.GBP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]
2024-02-12 部品表整備
    [KZ80-TMS9918A-DRAM-1bit.csv, KZ80-TMS9918A.csv]
2024-02-12 README修正
2024-02-12 READMEにジャンパ設定追加
2024-02-18 64k版 部品配置調整、16k版 4164 DRAM対応版 ガーバーデータ出力
    [KZ80-TMS9918A-DRAM-1bit.GBL, KZ80-TMS9918A-DRAM-1bit.GBO, KZ80-TMS9918A-DRAM-1bit.GBP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]
2024-02-18 16k版 回路図PDF/jpeg 差し替え
